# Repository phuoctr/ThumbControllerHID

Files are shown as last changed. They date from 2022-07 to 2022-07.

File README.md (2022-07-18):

# Tutorial: Thumb-mounted controller

This thumb-mounted controller is an input device for use in extended reality (XR) environments, it operates by sensing its user’s thumb gestures in which thumb contact and movements are processed using various output data. This data is gathered from 2 or more force sensitive resistors and a gyroscope. Recognised gestures are then sent to an XR device via Bluetooth Low Energy (BLE).
In this version, the Thumb-mounted controller uses Adafruit CircuitPython libraries for creating a BLE keyboard profile

## Materials
### Seeed Xiao BLE Sense
This is a BLE development board which comes with a built-in accelerator and gyroscope. The Xiao BLE Sense can be found on the [SEEED website](https://www.seeedstudio.com/Seeed-XIAO-BLE-Sense-nRF52840-p-5253.html).

### Force-Sensitive Resistors (FSRs) 
Two 30g minimum sensitivity resistors are recommended for better gesture recognition. The FSRs can be purchased quite readily but a 0-2kg sensitive FSR on [AliExpress](https://www.aliexpress.com/item/32853977086.html?spm=a2g0o.order_detail.0.0.274ef19cbF8s2J) is a good example.

### Resistors
Two 10,000Ω resistors are required for the controller to function properly. Wattage is not a concern for this device as the board has relatively low power consumption. The resistors can be purchased online fairly easily. However, for beginners, [this guide](https://wiraelectrical.com/10k-ohm-resistor-color-code/) shows the color code for the resistors.

### Li-Po Battery
For this controller, a 3.3V 25mAH battery is soldered on the board. For a more advanced setup, the controller can also be powered by a USB-C port. Without it, however, the battery will last for ~2 hours before it needs to be replaced. So it is up to the user's discretion to decide whether to use the USB-C port or the 25mAH battery.
> Note: The power consumption is not very significant, so some battery banks will only work for a few seconds before the controller loses power.

### 3D Printed Housing
This housing should be printed with [TPU filament](https://www.amazon.com/NinjaTek-3DNF01117505-NinjaFlex-Filament-Midnight/dp/B078JGZRCK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) (link is an example only) for better fitting. The `.stl` file for this housing can be found [here](Housing.stl).

## Controller Architecture
FSRs play an important role on this controller for touch recognition (i.e. swiping and pressing). To use the force sensors, we need to make a voltage divider circuit as shown in the figure below. 

<figure>

Force-Sensitive Resistors connected to a voltage divider

<figcaption align="center"><b>A 3V power contact is connected to one pin on each FSR while the other pin (the analog input and ground) is connected to the resistor.</b></figcaption>

</figure>

## Software Setup
To program the Adafruit Feather Sense board, a few setup steps are needed first.
1. [Set up CircuitPython on the Seeed board](https://wiki.seeedstudio.com/XIAO-BLE_CircutPython/)
2. Import `adafruit_ble` and `adafruit_lsm6ds` libraries. The documentation for these libraries can be found [here](https://docs.circuitpython.org/projects/ble/en/latest/) and [here](https://docs.circuitpython.org/projects/lsm6dsox/en/latest/api.html) respectively. The `adafruit_ble` library is used to create the BLE keyboard profile. The `adafruit_lsm6ds` library is used to create the accelerometer and gyroscope. To install the libraries, run the following command in a terminal:
```
pip3 install adafruit-circuitpython-ble adafruit-circuitpython-lsm6ds
```
> Note: A virtual environment is recommended for this setup. You can create one easily by following this [guide](https://realpython.com/python-virtual-environments-a-primer/#create-it).

## Hardware Details
The housing is comprised of two parts, one for holding the Xiao BLE Sense board and the other for mounting the user’s thumb. Under the thumb mount, the force sensitive pads of the two FSRs are stiched as illustrated in the figure below:

<figure>



<figcaption align="center"><b>The controller can be powered either by connecting to a computer or using an external battery. A battery wristband is designed for mounting the battery to the thumb mount.</b></figcaption>

</figure>

*See the [3D Printed Housing](#3d-printed-housing) section for more details on the housing.*

## Gestures
At the moment, this controller supports the following gestures:
- Swiping left/right
- Swiping up/down
- Quick press
- Long press

*More gestures will be added in the future.*

## Demo
A working demo for this controller can be found [here](https://soundxvision.io/lets-play-2048). In this demo, with the HID BLE profile uploaded to the board, I can use the thumb mounted controller for playing 2048.

## Contributions
This device was designed and developed by [SoundxVision](https://soundxvision.io) with this [thesis at VAMK](https://www.theseus.fi/handle/10024/744024) by [@phuoctr](https://github.com/phuoctr)  as a basis for the concept.

We would like to thank all of the contributors to this project.

<a href="https://github.com/phuoctr/ThumbControllerHID/graphs/contributors">
  
</a>

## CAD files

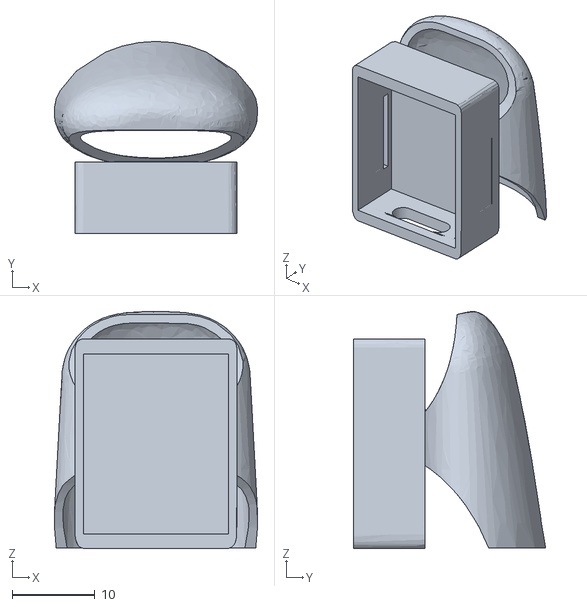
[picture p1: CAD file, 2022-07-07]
Housing.stl
24.5 x 23.2 x 28.6

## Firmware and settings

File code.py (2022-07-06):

# Write your code here :-)
# SPDX-FileCopyrightText: 2020 John Park for Adafruit Industries
#
# SPDX-License-Identifier: MIT

"""
This example acts as a BLE HID keyboard to peer devices.
Attach five buttons with pullup resistors to Feather nRF52840
  each button will send a configurable keycode to mobile device or computer
"""

import time
import board
from analogio import AnalogIn

import board
import digitalio
import busio
from adafruit_lsm6ds.lsm6ds3trc import LSM6DS3TRC
from adafruit_lsm6ds import Rate, AccelRange, GyroRange

# LSM6DS3TRC
# On the Seeed XIAO nRF52840 Sense the LSM6DS3TR-C IMU is connected on a separate
# I2C bus and it has its own power pin that we need to enable.
imupwr = digitalio.DigitalInOut(board.IMU_PWR)
imupwr.direction = digitalio.Direction.OUTPUT
imupwr.value = True
time.sleep(0.1)

imu_i2c = busio.I2C(board.IMU_SCL, board.IMU_SDA)
sensor = LSM6DS3TRC(imu_i2c)
sensor.gyro_range = GyroRange.RANGE_2000_DPS

# BLE

import adafruit_ble
from adafruit_ble.advertising import Advertisement
from adafruit_ble.advertising.standard import ProvideServicesAdvertisement
from adafruit_ble.services.standard.hid import HIDService
from adafruit_ble.services.standard.device_info import DeviceInfoService
from adafruit_hid.keyboard import Keyboard
from adafruit_hid.keyboard_layout_us import KeyboardLayoutUS
from adafruit_hid.keycode import Keycode

hid = HIDService()

device_info = DeviceInfoService(
    software_revision=adafruit_ble.__version__, manufacturer="SoundxVision"
)
advertisement = ProvideServicesAdvertisement(hid)
advertisement.appearance = 961
scan_response = Advertisement()
scan_response.complete_name = "SxV HID"

ble = adafruit_ble.BLERadio()
if not ble.connected:
    #print("advertising")
    ble.start_advertising(advertisement, scan_response)
else:
    #print("already connected")
    #print(ble.connections)
    ble.connections

# keyboard service

k = Keyboard(hid.devices)
kl = KeyboardLayoutUS(k)

# Touch sensing mechanic

AIN0 = AnalogIn(board.A0)
AIN2 = AnalogIn(board.A2)

# HID HIDState
IDLING = 0
FIRST_ZONE_TOUCH = 1
FIRST_ZONE_START_PRESS = 2
FIRST_ZONE_PRESS_DOWN = 3
FIRST_ZONE_RELEASE = 4
SECOND_ZONE_TOUCH = 5
SECOND_ZONE_START_PRESS = 6
SECOND_ZONE_PRESS_DOWN = 7
SECOND_ZONE_RELEASE = 8
UP = 9
DOWN = 10
LEFT = 11
RIGHT = 12

# Force sensor ranges
NONE_CONTACT = 10
PRESS_DOWN = 500

# Duration
MIN_PRESS_DOWN_DURATION = 0.3
MAX_TOUCH_RELEASE = 0.05


# Initial HIDState of the device
HIDState = 0


pressDownTime = 0


timestampPress = 0
timestampRelease = 0
timestampSwipe = 0

# Swipe
SWIPING_UPDATE_INTERVAL = 0.350
SWIPING_ANGLE = 4
touchReleaseTime = MAX_TOUCH_RELEASE
swipeTime = SWIPING_UPDATE_INTERVAL
firstZoneLeft = False
firstZoneRight = False
secondZoneLeft = False
secondZoneRight = False

# Rotation
zAxisRotation = 0


while True:
    # Advertising
    while not ble.connected:
        pass

    # Once connected
    while ble.connected:
        fsr0 = AIN0.value / 64
        fsr1 = AIN2.value / 64
        if HIDState == IDLING:
            if fsr0 > NONE_CONTACT and fsr1 > NONE_CONTACT:
                pass
            if fsr0 > NONE_CONTACT:
                HIDState = FIRST_ZONE_TOUCH
                timestampSwipe = time.monotonic()
            if fsr1 > NONE_CONTACT:
                HIDState = SECOND_ZONE_TOUCH

        elif HIDState == FIRST_ZONE_TOUCH:
            if fsr0 <= NONE_CONTACT:
                if firstZoneLeft:
                    k.send(Keycode.LEFT_ARROW)
                    firstZoneLeft = False
                    # print("LEFT")
                    HIDState = IDLING

                elif firstZoneRight:
                    k.send(Keycode.RIGHT_ARROW)
                    # print("RIGHT")
                    firstZoneRight = False
                    HIDState = IDLING

                else:
                    HIDState = FIRST_ZONE_RELEASE
                    timestampRelease = time.monotonic()
            elif fsr0 >= PRESS_DOWN:
                HIDState = FIRST_ZONE_START_PRESS
                timestampPress = time.monotonic()
            else:
                if swipeTime >= 0:
                    zAxisRotation += (
                        sensor.gyro[2] * 57.2958 * (time.monotonic() - timestampSwipe)
                    )
                    swipeTime -= time.monotonic() - timestampSwipe
                    timestampSwipe = time.monotonic()
                    if zAxisRotation >= SWIPING_ANGLE:
                        firstZoneLeft = True
                        zAxisRotation = 0
                    elif zAxisRotation <= -SWIPING_ANGLE:
                        firstZoneRight = True
                        zAxisRotation = 0
                else:
                    swipeTime = SWIPING_UPDATE_INTERVAL
                    zAxisRotation = 0
                    firstZoneLeft = False
                    firstZoneRight = False

        elif HIDState == FIRST_ZONE_START_PRESS:
            if fsr0 >= PRESS_DOWN:
                pressDownTime += time.monotonic() - timestampPress
                timestampPress = time.monotonic()
            elif fsr0 <= PRESS_DOWN:
                HIDState = IDLING
            if pressDownTime >= MIN_PRESS_DOWN_DURATION:
                HIDState = FIRST_ZONE_PRESS_DOWN

        elif HIDState == FIRST_ZONE_PRESS_DOWN:
            # print("1st Press")
            k.send(Keycode.ENTER)
            HIDState = IDLING
            pressDownTime = 0

        elif HIDState == FIRST_ZONE_RELEASE:
            # print("1st Released! ", touchReleaseTime)
            touchReleaseTime -= time.monotonic() - timestampRelease
            timestampRelease = time.monotonic()
            if touchReleaseTime > 0:
                if fsr1 > NONE_CONTACT:
                    HIDState = UP
            else:
                HIDState = IDLING
                touchReleaseTime = MAX_TOUCH_RELEASE

        elif HIDState == SECOND_ZONE_TOUCH:
            if fsr1 <= NONE_CONTACT:
                if secondZoneLeft:
                    k.send(Keycode.LEFT_ARROW)
                    firstZoneLeft = False
                    # print("LEFT")
                    HIDState = IDLING
                elif secondZoneRight:
                    k.send(Keycode.RIGHT_ARROW)
                    # print("RIGHT")
                    firstZoneRight = False
                    HIDState = IDLING
                else:
                    HIDState = SECOND_ZONE_RELEASE
                    timestampRelease = time.monotonic()
            elif fsr1 >= PRESS_DOWN:
                HIDState = SECOND_ZONE_START_PRESS
                timestampPress = time.monotonic()
            else:
                if swipeTime >= 0:
                    zAxisRotation += (
                        sensor.gyro[2] * 57.2958 * (time.monotonic() - timestampSwipe)
                    )
                    swipeTime -= time.monotonic() - timestampSwipe
                    timestampSwipe = time.monotonic()
                    if zAxisRotation >= SWIPING_ANGLE:
                        secondZoneLeft = True
                        zAxisRotation = 0
                    elif zAxisRotation <= -SWIPING_ANGLE:
                        secondZoneRight = True
                        zAxisRotation = 0
                else:
                    swipeTime = SWIPING_UPDATE_INTERVAL
                    zAxisRotation = 0
                    secondZoneLeft = False
                    secondZoneRight = False

        elif HIDState == SECOND_ZONE_START_PRESS:
            if fsr1 >= PRESS_DOWN * 0.7:
                pressDownTime += time.monotonic() - timestampPress
                timestampPress = time.monotonic()
            elif fsr1 <= PRESS_DOWN:
                HIDState = IDLING
            if pressDownTime >= MIN_PRESS_DOWN_DURATION:
                HIDState = SECOND_ZONE_PRESS_DOWN

        elif HIDState == SECOND_ZONE_PRESS_DOWN:
            # print("2ND Press")
            k.send(Keycode.ESCAPE)
            HIDState = IDLING
            pressDownTime = 0

        elif HIDState == SECOND_ZONE_RELEASE:
            # print("2ND Released! ", touchReleaseTime)
            touchReleaseTime -= time.monotonic() - timestampRelease
            timestampRelease = time.monotonic()
            if touchReleaseTime > 0:
                if fsr0 > NONE_CONTACT:
                    HIDState = DOWN
            else:
                HIDState = IDLING
                touchReleaseTime = MAX_TOUCH_RELEASE

        elif HIDState == UP:
            pressDownTime = 0
            # print("UP")
            k.send(Keycode.UP_ARROW)
            HIDState = IDLING

        elif HIDState == DOWN:
            pressDownTime = 0
            # print("DOWN")
            k.send(Keycode.DOWN_ARROW)
            HIDState = IDLING

    ble.start_advertising(advertisement)

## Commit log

2022-07-07 Updated housing for the FSR version
    [Housing.stl]
2022-07-18 Edited battery information
